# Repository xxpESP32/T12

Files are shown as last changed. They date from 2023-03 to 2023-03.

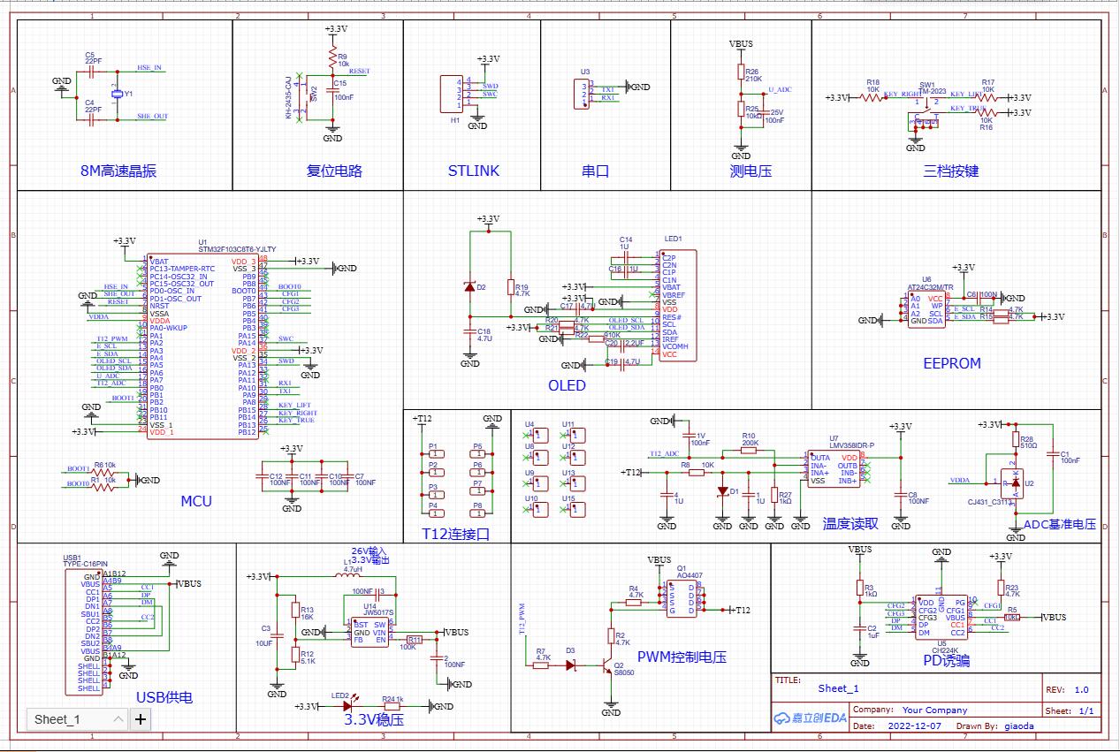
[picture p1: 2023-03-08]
硬件电路图/硬件原理图.jpg

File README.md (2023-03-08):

# T12
T12金乌电烙铁

--------------------------------------------------------------------------
成果展示
  313B5EF68EEE2CF83EF57E285038C913
  D6C2F57D7B10614ED86223D6952B662B

--------------------------------------------------------------------------

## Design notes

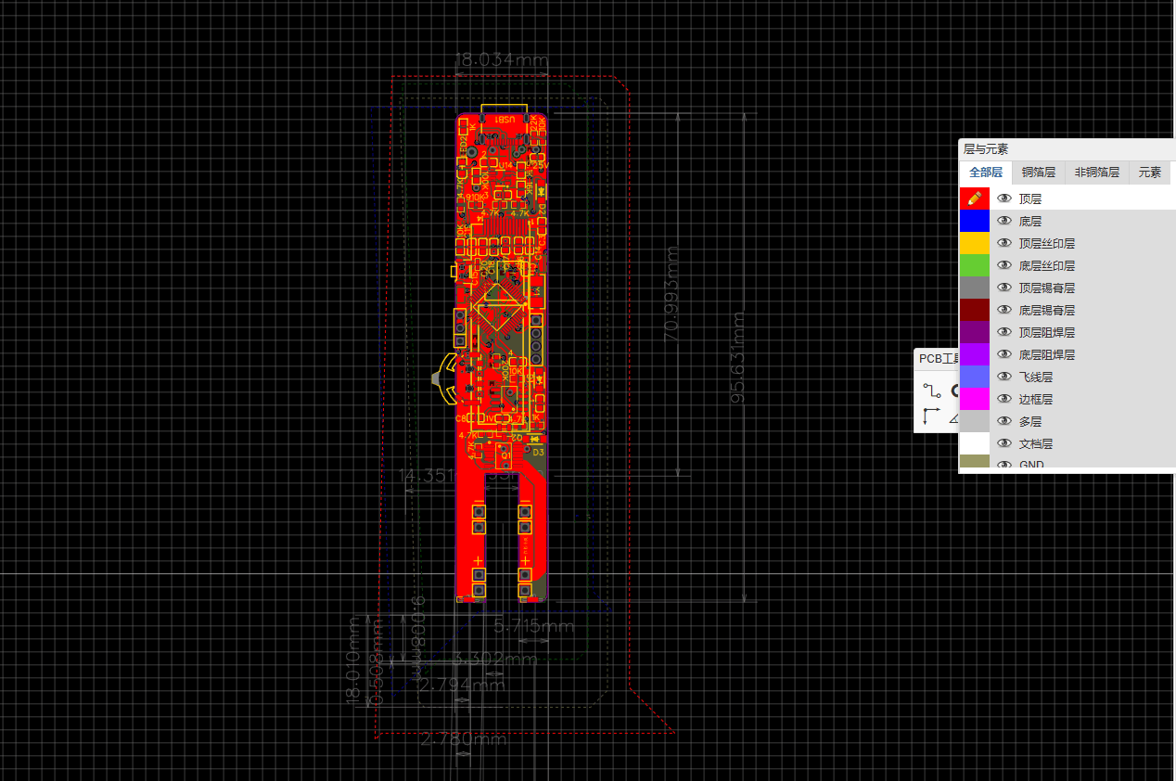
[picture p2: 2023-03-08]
硬件电路图/PCB图.png

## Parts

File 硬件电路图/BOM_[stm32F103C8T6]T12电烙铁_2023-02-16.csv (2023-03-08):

ID | Name | Designator | Footprint | Quantity | Manufacturer Part | Manufacturer | Supplier | Supplier Part | Price | Pins
1 | 1U | 1,4,C14,C16 | C0603 | 4 |  |  |  |  |  | 2
2 | 100nF | 1V,25V,C1 | C0603 | 3 | CL10B104KC8NNNC | SAMSUNG | LCSC | C15725 | 0.0462 | 2
3 | 100NF | 2,3,C7,C8,C10,C11,C12 | C0603 | 7 |  |  |  |  |  | 2
4 | 1uF | C2 | C0603 | 1 | CC0603KRX5R8BB105 | YAGEO | LCSC | C14664 | 0.0331 | 2
5 | 10UF | C3 | C0603 | 1 |  |  |  |  |  | 2
6 | 22PF | C4,C5 | C0603 | 2 |  |  |  |  |  | 2
7 | 100N | C6 | C0603 | 1 |  |  |  |  |  | 2
8 | 100nF | C15 | C0402 | 1 | GCM155R71C104KA55J | muRata(村田) | LCSC | C2655418 | 0.0395 | 2
9 | 4.7U | C17,C18,C19 | C0603 | 3 |  |  |  |  |  | 2
10 | 2.2UF | C20 | C0603 | 1 |  |  |  |  |  | 2
11 | 1N5819HW-7-F | D1,D2,D3 | SOD-123_L2.8-W1.8-LS3.7-FD | 3 | 1N5819HW-7-F | DIODES | LCSC | C82544 | 0.1569 | 2
12 | 220S-1*4P H=8.5MM Ytype Gold-plated | H1 | DIP-1X4P2.54 | 1 | 220S-1*4P H=8.5MM Ytype Gold-plated | Ckmtw | LCSC | C124413 | 0.7241 | 4
13 | 4.7uH | L1 | IND-SMD_L4.9-W4.4_MAPM0420F | 1 | HA42-4R7MT | FH(风华) | LCSC | C2936653 | 1.1026 | 2
14 | N091-2832TSWFG02-H14 | LED1 | OLED-SMD_N091-2832TSWFG02-H14 | 1 | N091-2832TSWFG02-H14 | Allvision(全智景) | LCSC | C2890599 | 18.83 | 14
15 | 204-10SURD/S530-A3 | LED2 | LED0805-RD | 1 | 204-10SURD/S530-A3 | EVERLIGHT | LCSC | C99772 | 0.2313 | 2
16 | Header-Male-2.54_1x1 | P1,P2,P3,P4,P5,P6,P7,P8 | HDR-TH_1P-P2.54-V-M | 8 | 2.54-1*1P针 | BOOMELE(博穆精密) | LCSC | C81276 | 0.0405 | 1
17 | AO4407 | Q1 | SOP-8_L5.0-W4.0-P1.27-LS6.0-BL | 1 | AO4407 | KEXIN(科信) | LCSC | C382328 | 1.2675 | 8
18 | S8050 | Q2 | SOT-23-3_L2.9-W1.3-P1.90-LS2.4-BR | 1 | S8050 | Doeshare（德芯) | LCSC | C2931719 | 0.0917 | 3
19 | 10k | R1,R6,R9 | R0603 | 3 |  |  |  |  |  | 2
20 | 4.7K | R2,R4,R7,R14,R15,R19,R20,R21,R23 | R0603 | 9 | RMC06036.8K5%N | Tyohm | LCSC | C269697 | 0.019 | 2
21 | 1kΩ | R3,R27 | R0603 | 2 | MCWF06R1001BTL | Multicomp | LCSC | C241300 | 1.4764 | 2
22 | 10kΩ | R5,R25 | R0603 | 2 | RMC06036.8K5%N | Tyohm | LCSC | C269697 | 0.019 | 2
23 | 10K | R8 | R0603 | 1 | MCWF06R1001BTL | Multicomp | LCSC | C241300 | 1.4764 | 2
24 | 200K | R10 | R0603 | 1 | MCWF06R1001BTL | Multicomp | LCSC | C241300 | 1.4764 | 2
25 | 100K | R11 | R0603 | 1 |  |  |  |  |  | 2
26 | 5.1K | R12 | R0603 | 1 |  |  |  |  |  | 2
27 | 16K | R13 | R0603 | 1 |  |  |  |  |  | 2
28 | 10K | R16,R17,R18 | R0603 | 3 |  |  |  |  |  | 2
29 | 910K | R22 | R0603 | 1 | RMC06036.8K5%N | Tyohm | LCSC | C269697 | 0.019 | 2
30 | 1k | R24 | R0603 | 1 |  |  |  |  |  | 2
31 | 210K | R26 | R0603 | 1 | RMC06036.8K5%N | Tyohm | LCSC | C269697 | 0.019 | 2
32 | 510Ω | R28 | R0603 | 1 | 0603WAJ0000T5E | UniOhm | LCSC | C15402 | 0.0067 | 2
33 | TM-2023 | SW1 | SW-SMD_TM-2023-1 | 1 | TM-2023 | XKB Enterprise | LCSC | C318951 | 1.7524 | 8
34 | KH-2435-CAJ | SW2 | SW-SMD_KH-2435-CAJ | 1 | KH-2435-CAJ | kinghelm(金航标) | LCSC | C530669 | 0.2322 | 4
35 | STM32F103C8T6-YJLTY | U1 | QFP-48_L7.0-W7.0-P0.50-LS9.0-BL | 1 | STM32F103C8T6-YJLTY | null | LCSC | C2911485 |  | 48
36 | CJ431_C3113 | U2 | SOT-23-3_L2.9-W1.6-P1.90-LS2.8-BR | 1 | CJ431 | CJ | LCSC | C3113 | 0.2165 | 3
37 | 排母2.54MM 1X3PIN | U3 | HDR-TH_3P-P2.54_CS-1165SDIG | 1 | 排母2.54mm 1X3pin | null | LCSC | C9900016709 |  | 3
38 | BW0033AG-L3.4W0.9H1.8 | U4,U8,U9,U10,U11,U12,U13,U15 | TESTPOINT-SMD_L3.4-W0.9_BW0033AG | 8 | BW0033AG-L3.4W0.9H1.8 | BAT WIRELESS(蝙蝠无线) | LCSC | C2826530 | 0.1192 | 1
39 | CH224K | U5 | ESOP-10_L4.9-W3.9-P1.00-LS6.2-BL-EP | 1 | CH340K | WCH(Jiangsu Qin Heng) | LCSC | C968586 | 4.46 | 11
40 | AT24C32M/TR | U6 | SOP-8_L4.9-W3.9-P1.27-LS6.0-BL | 1 | AT24C32M/TR | HGSEMI(华冠) | LCSC | C2688466 | 0.8664 | 8
41 | LMV358IDR-P | U7 | SOP-8_L4.9-W3.9-P1.27-LS6.0-BL | 1 | LMV358IDR-P | TECH PUBLIC(台舟) | LCSC | C2928703 | 0.7308 | 8
42 | JW5017S | U14 | SOT-23-6_L2.9-W1.6-P0.95-LS2.8-BR | 1 | JW5017S | Joulwatt(杰华特) | LCSC | C371172 | 0.7469 | 6
43 | TYPE-C16PIN | USB1 | USB-C-SMD_TYPE-C16PIN | 1 | TYPE-C16PIN | SHOU HAN | LCSC | C393939 | 1.3293 | 16
44 | SMD-5032_2P 8MHz 20ppm 20pF | Y1 | SMD-5032_2P | 1 |  |  | LC |  |  | 2

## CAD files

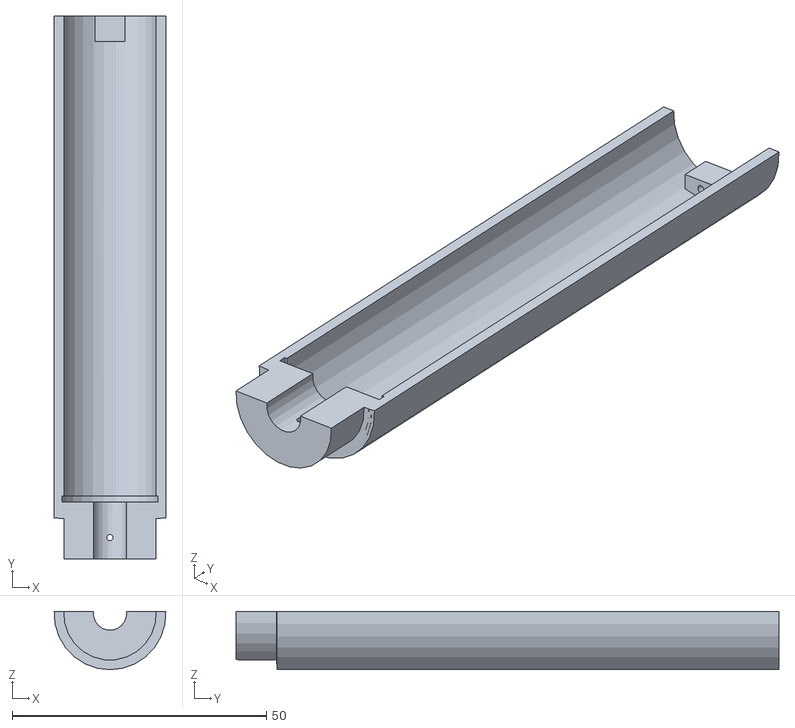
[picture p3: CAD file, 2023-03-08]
UG/NEW_STL/_model1.stl
22.0 x 106.8 x 11.5

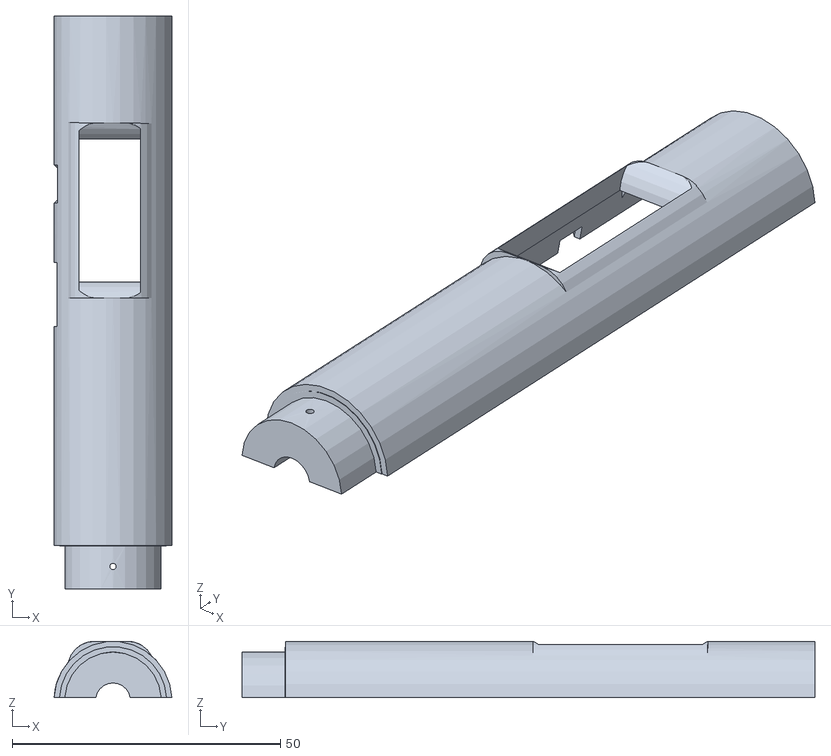
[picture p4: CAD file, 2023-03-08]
UG/NEW_STL/_model2.stl
22.0 x 106.8 x 10.5

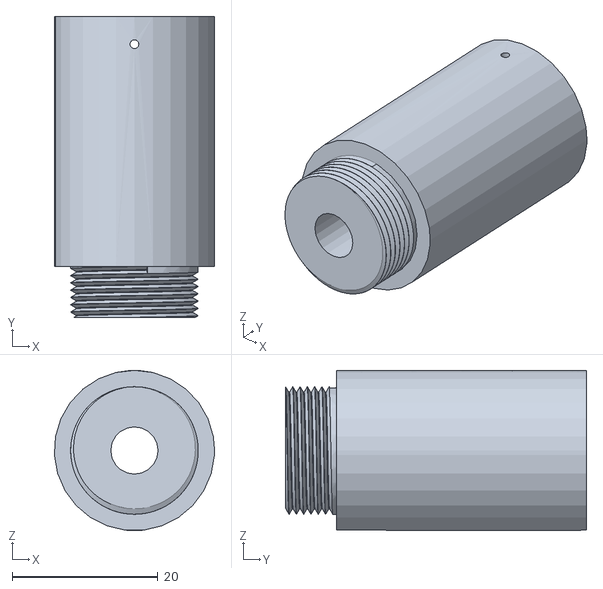
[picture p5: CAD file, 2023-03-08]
UG/NEW_STL/_model4.stl
22.0 x 41.3 x 22.0

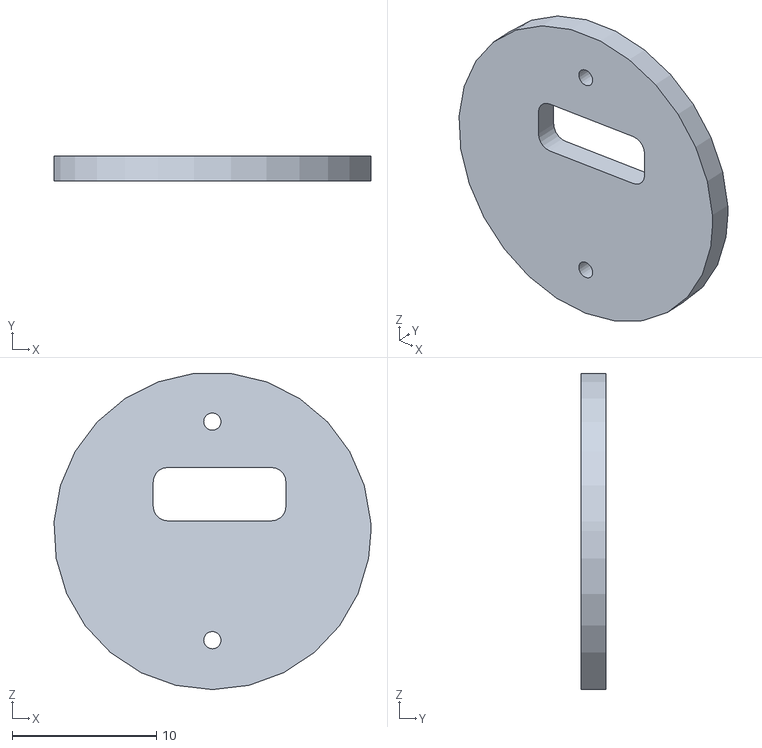
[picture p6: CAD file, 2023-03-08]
UG/NEW_STL/_model3.stl
22.0 x 1.70 x 21.9

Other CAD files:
UG/UG/ALL/_asm1.prt
UG/UG/BOOTNS/_model4.prt
UG/UG/NO_MUST/_model5.prt
UG/UG/NO_MUST/_model6.prt
UG/UG/TOPS/_model2.prt
UG/UG/TOPSS/_model3.prt
UG/UG/_model1.prt

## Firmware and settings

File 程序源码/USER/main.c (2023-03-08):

#include "delay.h"
#include "sys.h"
#include "oled.h"
//#include "bmp.h"
#include "PWM.h"
#include "KEY.h"
#include "ADC.h"
#include "FreeRTOS.h"
#include "task.h"
#include "CH224K.h"
#include "menu.h"
#include "Timer.h"
#include "Wire.h"
#include "AT24C32.h"
#include "Ui_Menu.h"
#include "usart.h"	
#include "stdio.h"
TaskHandle_t HandlerTask1;

StackType_t xIdle3Static[128];
StaticTask_t xIdleTCB;

void vApplicationGetIdleTaskMemory( StaticTask_t ** ppxIdleTaskTCBBuffer,StackType_t ** ppxIdleTaskStackBuffer,uint32_t * pulIdleTaskStackSize ){
			*ppxIdleTaskTCBBuffer=&xIdleTCB;				
			*ppxIdleTaskStackBuffer=xIdle3Static;
			*pulIdleTaskStackSize=128;
}

void Task1Function( void * param){ 
	
		for(;;){
      Menu_Loop();	  
		  vTaskDelay(200);
	}
}


void Task2Function(void* param){

  for(;;)
  {

		  
  }
}


int main(void)
{
	NVIC_PriorityGroupConfig(NVIC_PriorityGroup_4);
	
	delay_init();
	SystemInit();
	OLED_Init();

	PWM_init(1000,7200); //72MHz/72=1MHz=1000KHz=1us,100*1us=100us;//72/720=100KHZ,
	OLED_Clear();
	KEY_Begin();
	ADC_Begin();
	
	CH224K_Begin();

	TIM4_Begin(7000,7200); //300ms
	TIM3_Begin(10000,7200);//1000ms
  uart_init(115200);
	AT24C32_Begin();
	printf("%d\r\n",AT24C32_Check());
	T12_All_Set_Init();
	OLED_ColorTurn(skin_Flag);//0正常显示，1 反色显示
  OLED_DisplayTurn(rotation_Flag);//0正常显示 1 屏幕翻转显示
	//xTaskCreate(Task1Function,"Task1",100,NULL,2,&HandlerTask1);
  //xTaskCreate(Task2Function,"Task2",100,NULL,2,&HandlerTask1);
	//CH224K_Set_Output_Voltage(OUTPUT_5V);
  //vTaskStartScheduler(); //开始调度

	

	while(1)
	{
   
		 Key_Menu_Loop();
		//Menu_Loop();
		
	}
}

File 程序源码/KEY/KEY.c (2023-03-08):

#include "KEY.h"
#include "CH224K.h"
#include "menu.h"
#include "oled.h"
#include "FreeRTOS.h"
#include "task.h"
#include "Ui_Menu.h"
#include "AT24C32.h"
//********************************AT24C02存储地址
// 5 皮肤切换标志位
// 6 屏幕旋转
// 7 中英文切换
// 8 温度步数
// 9 低功耗时间
// 10 温度校准
u32 KEY_LEFT_FLAG=0;
u32 KEY_RIGHT_FLAG=0;
u32 KEY_ENTER_FLAG=0;

u16 T12_Set_Temp=300;
u8 Voltage_FLAG;
u8 rotation_Flag;
u8 C_E_cut_Flag;
u8 skin_Flag;


static void Calibrate_set_success(void);
static void rotation_set(void);
static void C_E_cut(void);
static void PD_Set(void);
static void skin_set(void);
static void calibration_add(u8 add_or_minus);
static void calibration_set_add_minus(u8 add_or_minus);
static void Low_power_Time_Value_set(u8 add_or_minus);
static void Low_power_Temp_Value_set(u8 add_or_minus);
static void Reset_set_success(void);

void KEY_Begin(void){
	GPIO_InitTypeDef GPIO_InitStructure;
	#if __IQR_POLL_
	EXTI_InitTypeDef EXTI_InitStructure;
	NVIC_InitTypeDef NVIC_InitStructure;
	#endif
	
	RCC_APB2PeriphClockCmd(RCC_APB2Periph_GPIOB|RCC_APB2Periph_AFIO,ENABLE);

	
  GPIO_InitStructure.GPIO_Mode=GPIO_Mode_IPU;
	GPIO_InitStructure.GPIO_Pin =KEY_LEFT|KEY_RIGHT|KEY_ENTER;
	GPIO_InitStructure.GPIO_Speed=GPIO_Speed_50MHz;
	GPIO_Init(GPIOB,&GPIO_InitStructure);
	#if __IQR_POLL_
	//EXTI_15的外部触发
	GPIO_EXTILineConfig(GPIO_PortSourceGPIOB,GPIO_PinSource15);
	EXTI_InitStructure.EXTI_Line =EXTI_Line15;
	EXTI_InitStructure.EXTI_Mode =EXTI_Mode_Interrupt;
	EXTI_InitStructure.EXTI_Trigger =EXTI_Trigger_Rising;
	EXTI_InitStructure.EXTI_LineCmd =ENABLE;
	EXTI_Init(&EXTI_InitStructure);

	//EXTI_14的外部触发
	GPIO_EXTILineConfig(GPIO_PortSourceGPIOB,GPIO_PinSource14);
	EXTI_InitStructure.EXTI_Line =EXTI_Line14;
	EXTI_InitStructure.EXTI_Mode =EXTI_Mode_Interrupt;
	EXTI_InitStructure.EXTI_Trigger =EXTI_Trigger_Rising;
	EXTI_InitStructure.EXTI_LineCmd =ENABLE;
	EXTI_Init(&EXTI_InitStructure);

	//EXTI_13的外部触发
	GPIO_EXTILineConfig(GPIO_PortSourceGPIOB,GPIO_PinSource13);
	EXTI_InitStructure.EXTI_Line =EXTI_Line13;
	EXTI_InitStructure.EXTI_Mode =EXTI_Mode_Interrupt;
	EXTI_InitStructure.EXTI_Trigger =EXTI_Trigger_Rising;
	EXTI_InitStructure.EXTI_LineCmd =ENABLE;
	EXTI_Init(&EXTI_InitStructure);
	//EXTI_13的中断
	
	NVIC_InitStructure.NVIC_IRQChannel =EXTI15_10_IRQn;
	NVIC_InitStructure.NVIC_IRQChannelPreemptionPriority =0;
	NVIC_InitStructure.NVIC_IRQChannelSubPriority =2;
	NVIC_InitStructure.NVIC_IRQChannelCmd =ENABLE;
	NVIC_Init(&NVIC_InitStructure);
	#endif
}
//******************************************中断方式***************************
#if __IQR_POLL_
void EXTI15_10_IRQHandler(void){
	delay_ms(200);
	if(EXTI_GetITStatus(EXTI_Line15)!=RESET){
			//delay_ms(200);
		//if(EXTI_GetITStatus(EXTI_Line15)!=RESET){
		 if(index_cp ==0){ //T12温度设置 加按键
			if(T12_Set_Temp>=420)
				T12_Set_Temp=420;
			else
				T12_Set_Temp+=Temperature_steps_Value;
		Temp_define_Flag=1;
		AT24C32_Write_OneByte(15,T12_Set_Temp);
		AT24C32_Write_OneByte(16,T12_Set_Temp>>8); 	
		OLED_Clear_Progress(64,3);//清除进度条
    }
		 
		calibration_add(0);
		calibration_set_add_minus(0);
		Low_power_Time_Value_set(0);
		Low_power_Temp_Value_set(0);
		
		if(index_cp !=0){
			OLED_Clear();
			//OLED_Clear_Progress(128,4);
			//OLED_Clear();
		}
		//delay_ms(10);
		index_cp=M_G[index_cp].next;
		//CH224K_Set_Output_Voltage(OUTPUT_9V);
		
	 		EXTI_ClearITPendingBit(EXTI_Line15);
			//	while(EXTI_GetFlagStatus(EXTI_Line15)!=RESET);
		//	EXTI_ClearFlag(EXTI_Line15); 
		//}
	}
	else if(EXTI_GetITStatus(EXTI_Line14)!=RESET){
		//delay_ms(200);
		//if(EXTI_GetITStatus(EXTI_Line14)!=RESET){
		if(index_cp ==0){ //T12温度设置 减按键
			if(T12_Set_Temp<=50)
				T12_Set_Temp=50;
			else
				T12_Set_Temp-=Temperature_steps_Value;
		Temp_define_Flag=1;
		AT24C32_Write_OneByte(15,T12_Set_Temp);
		AT24C32_Write_OneByte(16,T12_Set_Temp>>8);	
		OLED_Clear_Progress(64,3);//清除进度条
    }			
		calibration_add(1);
		calibration_set_add_minus(1);
		Low_power_Time_Value_set(1);
		Low_power_Temp_Value_set(1);
		
		if(index_cp !=0){
			OLED_Clear();	
			//OLED_Clear();
		}
				//delay_ms(10);
		index_cp=M_G[index_cp].back;

		//CH224K_Set_Output_Voltage(OUTPUT_20V);
		EXTI_ClearITPendingBit(EXTI_Line14);
		//while(EXTI_GetFlagStatus(EXTI_Line14)!=RESET);
		//EXTI_ClearFlag(EXTI_Line14);
	
	//	}
	}
	else if(EXTI_GetITStatus(EXTI_Line13)!=RESET){
		//delay_ms(200);
	  //if(EXTI_GetITStatus(EXTI_Line13)!=RESET){
		Calibrate_set_success();	
		rotation_set();
		C_E_cut();
		PD_Set();
		skin_set();
		Reset_set_success();
			OLED_Clear();
			//
		index_cp=M_G[index_cp].enter;
			
			


		EXTI_ClearITPendingBit(EXTI_Line13);
		//while(EXTI_GetFlagStatus(EXTI_Line13)!=RESET);
			//EXTI_ClearFlag(EXTI_Line13);
		//}
	}
  
}
#endif
//******************************************轮询方式***************************
void Key_Menu_Loop(void){
	if(GPIO_ReadInputDataBit(GPIOB,KEY_LEFT)==0){
			delay_ms(100);
		if(GPIO_ReadInputDataBit(GPIOB,KEY_LEFT)==0){
		 if(index_cp ==0){ //T12温度设置 加按键
			if(T12_Set_Temp>=420)
				T12_Set_Temp=420;
			else
				T12_Set_Temp+=Temperature_steps_Value;
		Temp_define_Flag=1;
		AT24C32_Write_OneByte(15,T12_Set_Temp);
		AT24C32_Write_OneByte(16,T12_Set_Temp>>8); 	
		OLED_Clear_Progress(64,3);//清除进度条
    }
		 
		calibration_add(0);
		calibration_set_add_minus(0);
		Low_power_Time_Value_set(0);
		Low_power_Temp_Value_set(0);
		
		if(index_cp !=0){
			OLED_Clear();
		}

		index_cp=M_G[index_cp].next;

		}
	}
	else if(GPIO_ReadInputDataBit(GPIOB,KEY_RIGHT)==0){
		delay_ms(100);
		if(GPIO_ReadInputDataBit(GPIOB,KEY_RIGHT)==0){
		if(index_cp ==0){ //T12温度设置 减按键
			if(T12_Set_Temp<=50)
				T12_Set_Temp=50;
			else
				T12_Set_Temp-=Temperature_steps_Value;
		Temp_define_Flag=1;
		AT24C32_Write_OneByte(15,T12_Set_Temp);
		AT24C32_Write_OneByte(16,T12_Set_Temp>>8);	
		OLED_Clear_Progress(64,3);//清除进度条
    }			
		calibration_add(1);
		calibration_set_add_minus(1);
		Low_power_Time_Value_set(1);
		Low_power_Temp_Value_set(1);
		
		if(index_cp !=0){
			OLED_Clear();	
		}

		index_cp=M_G[index_cp].back;


	
		}
	}
	else if(GPIO_ReadInputDataBit(GPIOB,KEY_ENTER)==0){
		delay_ms(200);
	  if(GPIO_ReadInputDataBit(GPIOB,KEY_ENTER)==0){
		Calibrate_set_success();	
		rotation_set();
		C_E_cut();
		PD_Set();
		skin_set();
		Reset_set_success();
			OLED_Clear();
			//
		index_cp=M_G[index_cp].enter;
			
			

		}
	}
	Menu_Loop();	
}

//校准成功显示
static void Calibrate_set_success(void){
	if(index_cp ==9){
		
		OLED_Clear();
		if(C_E_cut_Flag ==0){
			OLED_Draw_Rect(28,4,68,24,1);
			OLED_ShowChinese(32,8,29,16,1);//温
			OLED_ShowChinese(16+32,8,30,16,1);//度
			OLED_ShowChinese(32+32,8,31,16,1);//步
			OLED_ShowChinese(48+32,8,32,16,1);//数
		}else{
			OLED_Draw_Rect(30,4,64,24,1);		
			OLED_ShowString(35,8,"Calibrate",8,1);
			OLED_ShowString(43,16,"Success",8,1);			
		}
		OLED_Refresh();
		AT24C32_Write_OneByte(10,Calibrate_Value);
		AT24C32_Write_OneByte(14,Calibrate_Value>>8);    		
		delay_ms(1000);
	}
}
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
